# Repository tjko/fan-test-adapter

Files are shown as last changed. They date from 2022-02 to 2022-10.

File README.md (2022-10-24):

# fan-test-adapter
Adapter PCB board for easily testing PC (PWM) fans.

Adapter was created to simplify characterising PC fans. It's mainly meant for PWM fans, but can also be useful for 3-pin PC fans. Adapter also has common JST connectors for common 2-pin fans.
This adapter was used in development and testing of [Fanpico](https://github.com/tjko/fanpico/) (Fanpico is a smart PWM fan controller) to "emulate" motherboard FAN outputs.

Adapter is meant to be used with
* 3 channel programmable power supply (but will work fine with 1 or 2 channel PSUs)
* 2+ channel oscilloscope (or frequency counter)
* 2 channel signal generator

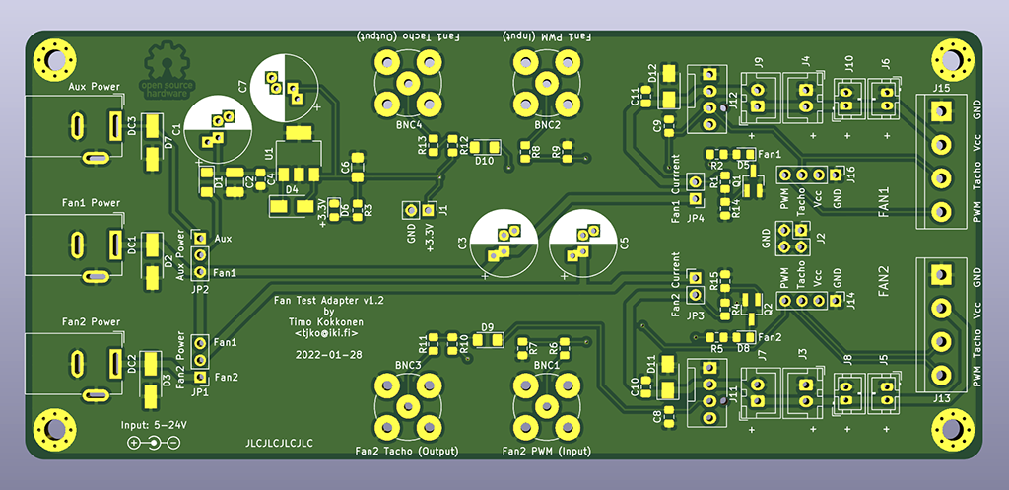
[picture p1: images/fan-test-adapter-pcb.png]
Fan Test Adapter PCB


Assembled fan test adapter:
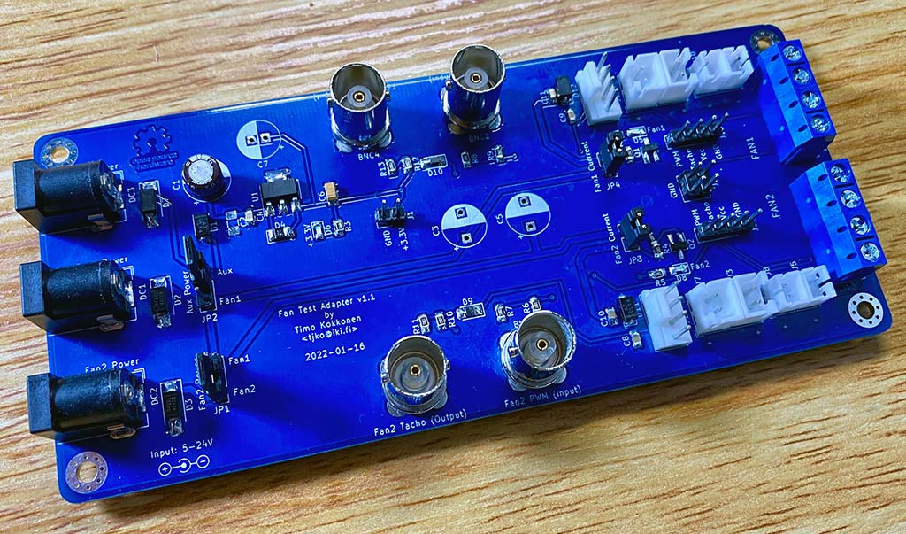
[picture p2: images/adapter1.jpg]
Assembled Fant Test Adapter


Fan test adapter in use:
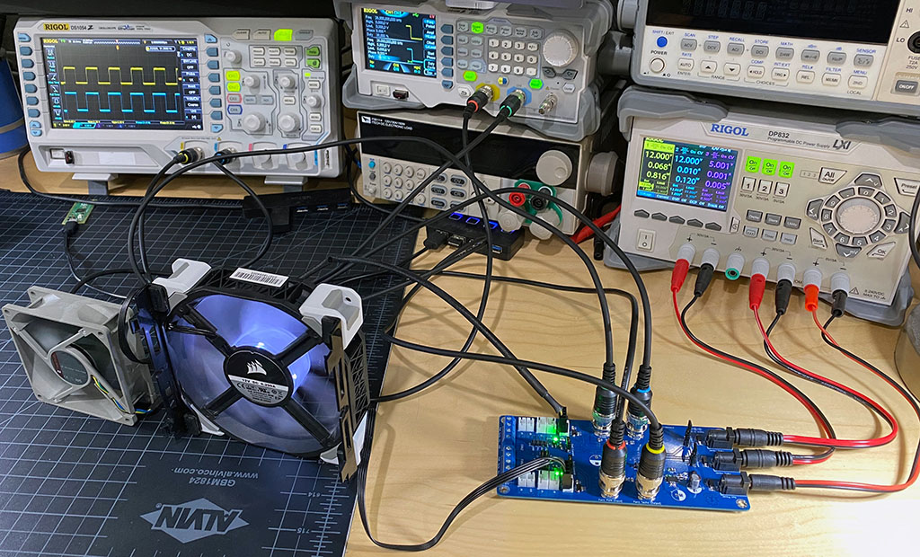
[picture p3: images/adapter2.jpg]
Fan Test Adapter in use


## Usage Notes
This is only adapter for easily testing/controlling PWM fans. If used incorrectly it could easily damage your fans, etc...

### Power Connectors
Fan Test Adapter has three DC power jacks. It can be used only with power supplied to "Fan1 Power" jack, but it may be desirable to use all three, depending on how adapter is being used.

#### AUX Power
This is can be used to power the board itself (3.3V power rail, LEDs, etc). This can be useful if doing fan power consumption measurements via measuring supplied power to Fan1/Fan2 connectors.
When using this connector make sure jumper _Aux Power_ is set to _Aux_ position (and _Fan2 Power_ jumper is set to _Fan2_ position).

Recommended supply voltage is 5V (however up to 24V can be used if needed).

#### Fan1 Power
This is used to provide power to Fan1. Additionally _Aux Power_ jumper can be set to _Fan1_ position if _AUX Power_ is not used.

Recommended supply voltage is the nominal voltage of the fan being tested (Voltage should be in range from 5V to 24V max).

#### Fan2 Power
This is used to proive power fo Fan1.  If this connector is used remember to set _Fan2 Power_ jumper to _Fan2_ position.

Recommended supply voltage is the nominal voltage of the fan being tested (Voltage should be in range from 5V to 24V max).

### Jumpers

#### Fan1 Current
Normally closed. Can be used for precise current measurement of Fan1 power consumption, by removing the jumper and connecting current meter in the pins.
#### Fan2 Current
Normally closed. Can be used for precise current measurement of Fan2 power consumption, by removing the jumper and connecting current meter in the pins.
#### Aux Power
Jumper to select whether board itself (3.3V power rail) is powered from _Fan1 Power_ or _Aux Power_ power connector.
#### Fan2 Power
Jumper to select whether Fan2 is powered from _Fan1 Power_ or _Fan2 Power_ power connector.

### BNC Connectors
#### Fan1/Fan2 PWM (Input)
Input for PWM signal to control fan speed. Typically (with PC fans) this is 25kHz PWM signal (0-5V).

#### Fan1/Fan2 Tacho (Output)
Adapter generates 3.3V TTL signal from the open collector tachometer output of the fan. So this is generally safe to be read direcly with a 3.3V (or 5V) MCU.

## Building Notes
* See [PCB](#pcb-kerbers) section for how to get PCB manufactured (currently it is only few dollars pre PCB to have these manufactured).
* List of needed components can be found here: [BOM](fan-test-adapter-bom.csv)
* Some of the components are optional (but can offer some protection) for details see: [Schematic](fan-test-adapter.pdf)

### PCB (Kerbers)
Kerber files ready to be sent to a PCB maker (like JLCPCB, etc):
* [PCB Version 1.2](kerbers/fan-test-adapter-v1.2.zip)

### Where to buy?
Currently this is only a DIY project. However PCBs are occasionally available (in limited quantities) at: [eBay](https://www.ebay.com/usr/oh6lxv)

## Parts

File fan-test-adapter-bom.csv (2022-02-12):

Ref | QTY | Value | Cmp name | Footprint | Description | Vendor | Mouser | LCSC
BNC1, BNC2, BNC3, BNC4 | 4 | 5-1634503-1 | Conn_Coaxial | Connector_Coaxial:BNC_TEConnectivity_1478204_Vertical | coaxial connector (BNC, SMA, SMB, SMC, Cinch/RCA, LEMO, ...) | TE | 571-5-1634503-1
C1 | 1 | 4.7uF 35V (DNF) | CP | Capacitor_THT:CP_Radial_D10.0mm_P2.50mm_P5.00mm
C2, | 1 | 4.7uF 35V | CP | Capacitor_SMD:C_1210_3225Metric_Pad1.42x2.65mm_HandSolder | Tantalum |  | 581-TAJB475K035R
C4, C10, C11, | 3 | 0.1uF 35V | C | Capacitor_SMD:C_0805_2012Metric_Pad1.15x1.40mm_HandSolder | Unpolarized capacitor
C6, | 1 | 10uF 16V | CP | Capacitor_SMD:C_1206_3216Metric_Pad1.42x1.75mm_HandSolder | Tantalum |  |  | C880927
C7, | 1 | 10uF 16V (DNF) | CP | Capacitor_THT:CP_Radial_D10.0mm_P2.50mm_P5.00mm
C8, C9, | 2 | 1nF | C | Capacitor_SMD:C_0805_2012Metric_Pad1.15x1.40mm_HandSolder | Unpolarized capacitor
D1, D9, D10, | 3 | SM5819PL-TP | D | Diode_SMD:D_1206_3216Metric_Pad1.42x1.75mm_HandSolder | Diode |  |  | C669023
D2, D3, D7, | 3 | SBRT5A50SA | D | Diode_SMD:D_SMA_Handsoldering | Diode |  |  | C264107
D4, D11, D12, | 3 | FM4007W | D | Diode_SMD:D_SMA | Diode |  |  | C402244
D5, D6, D8, | 3 | LED | LED | LED_SMD:LED_0805_2012Metric_Pad1.15x1.40mm_HandSolder | Light emitting diode |  |  | C434432
DC1, DC2, DC3 | 3 | DC Jack | Barrel_Jack_Switch | Connector_BarrelJack:BarrelJack_Wuerth_6941xx301002 | DC Barrel Jack with an internal switch |  |  | C720558
J3, J4, J7, J9 | 4 | JST XH | Conn_01x02_Male | Connector_JST:JST_XH_B2B-XH-A_1x02_P2.50mm_Vertical |  |  |  | C158012
J5, J6, J8, J10 | 4 | JST PH | Conn_01x02_Male | Connector_JST:JST_PH_B2B-PH-K_1x02_P2.00mm_Vertical |  |  |  | C131337
J11, J12 | 2 | 47053-1000 | Fan_CPU_4pin | Connector:FanPinHeader_1x04_P2.54mm_Vertical | CPU Fan, tacho output, PWM input, 4-pin connector | Molex | 538-47053-1000
J13, J15 | 2 | Terminal Block | Conn_01x04_Male | TerminalBlock:TerminalBlock_bornier-4_P5.08mm |  |  |  | C1509679
Q1, Q2, | 2 | 2N7002K | 2N7002K | Package_TO_SOT_SMD:SOT-23_Handsoldering | 0.38A Id, 60V Vds, N-Channel MOSFET, SOT-23 |  |  | C85047
R1, R4, | 2 | 100k | R | Resistor_SMD:R_0805_2012Metric_Pad1.15x1.40mm_HandSolder | Resistor
R2, R3, R5, | 3 | 5k | R | Resistor_SMD:R_0805_2012Metric_Pad1.15x1.40mm_HandSolder | Resistor
R6, R8, R11, R13, | 4 | 1k | R | Resistor_SMD:R_0805_2012Metric_Pad1.15x1.40mm_HandSolder | Resistor
R7, R9, | 2 | 33k | R | Resistor_SMD:R_0805_2012Metric_Pad1.15x1.40mm_HandSolder | Resistor
R10, R12, | 2 | 10k | R | Resistor_SMD:R_0805_2012Metric_Pad1.15x1.40mm_HandSolder | Resistor
R14, R15, | 2 | 1M | R | Resistor_SMD:R_0805_2012Metric_Pad1.15x1.40mm_HandSolder | Resistor
U1, | 1 | SPX2954-3.3 | SPX2954-3.3 | Package_TO_SOT_SMD:SOT-223-3_TabPin2 | 400mA Low drop-out regulator, Fixed Output 3.3V, SOT-223 |  |  | C32770
Jumpers | 4 | 2.54mm jumper |  |  |  |  |  | C5305

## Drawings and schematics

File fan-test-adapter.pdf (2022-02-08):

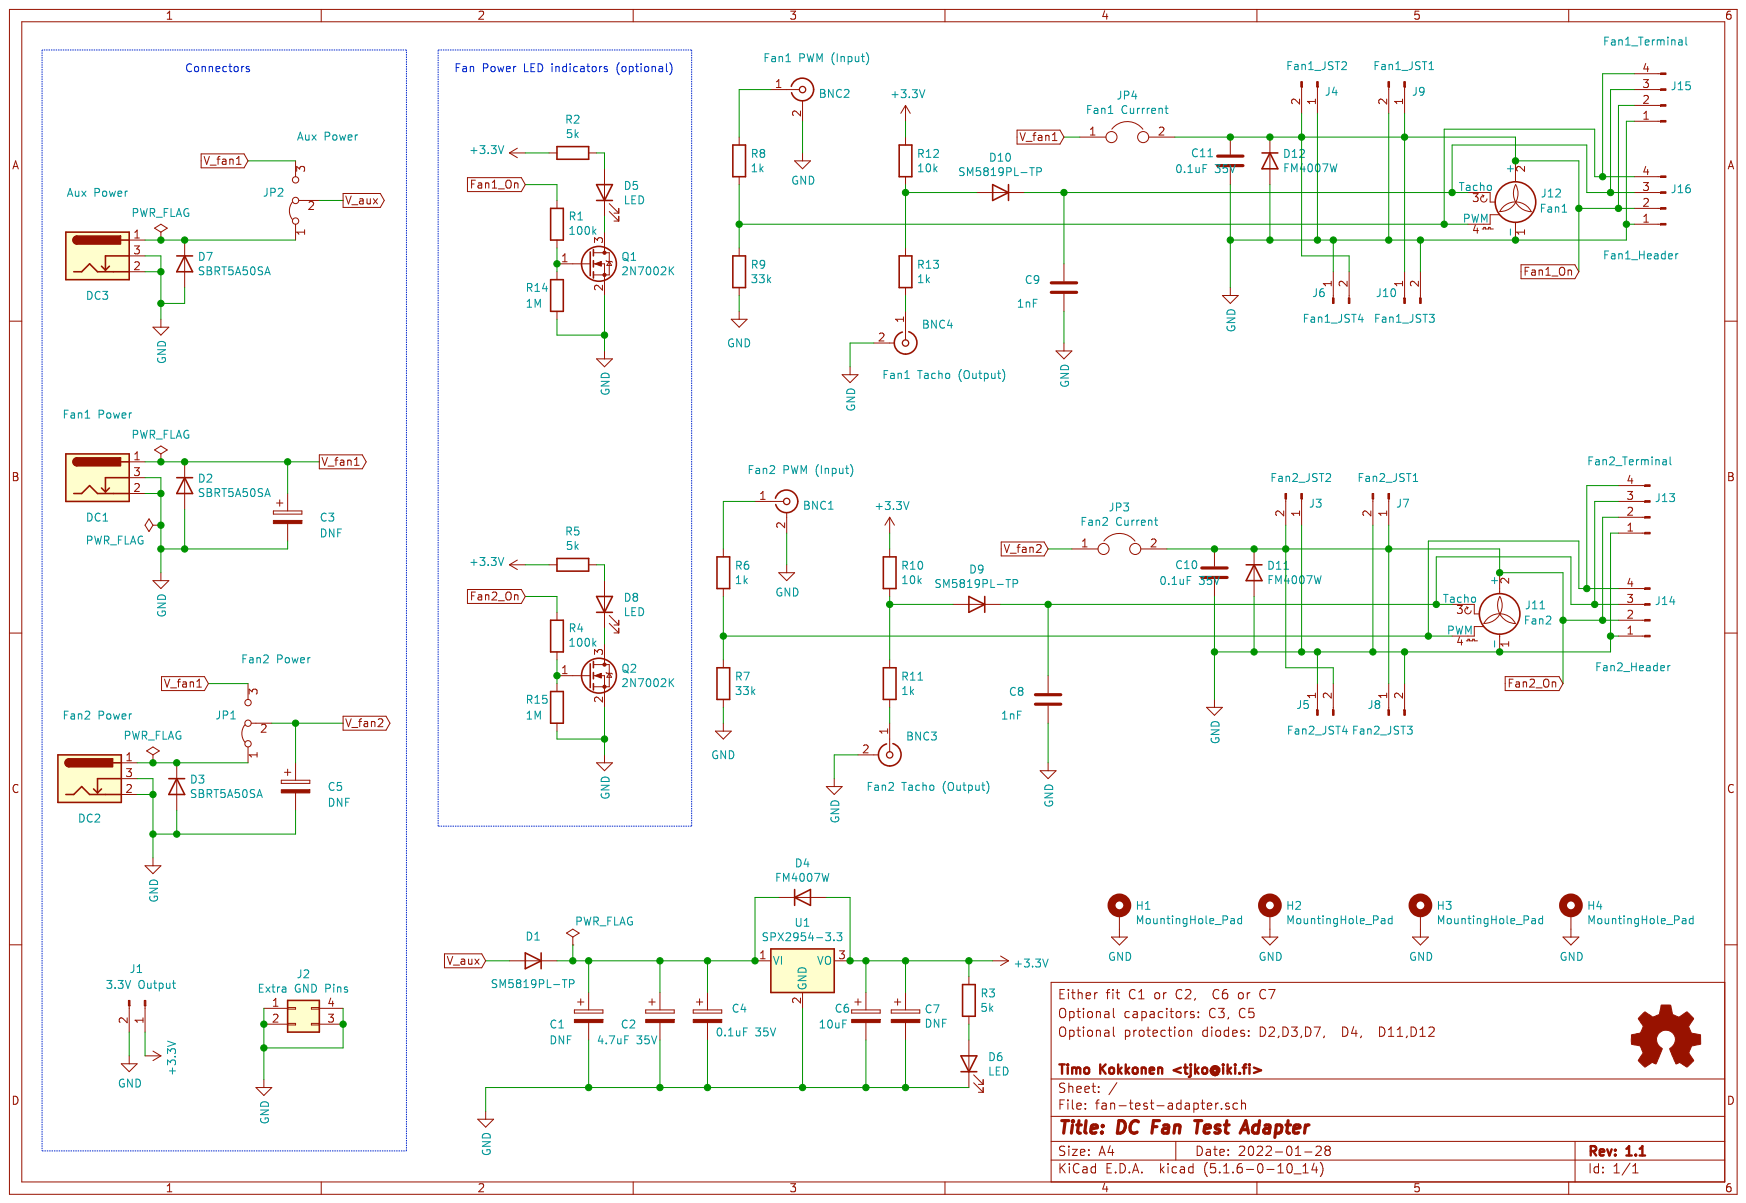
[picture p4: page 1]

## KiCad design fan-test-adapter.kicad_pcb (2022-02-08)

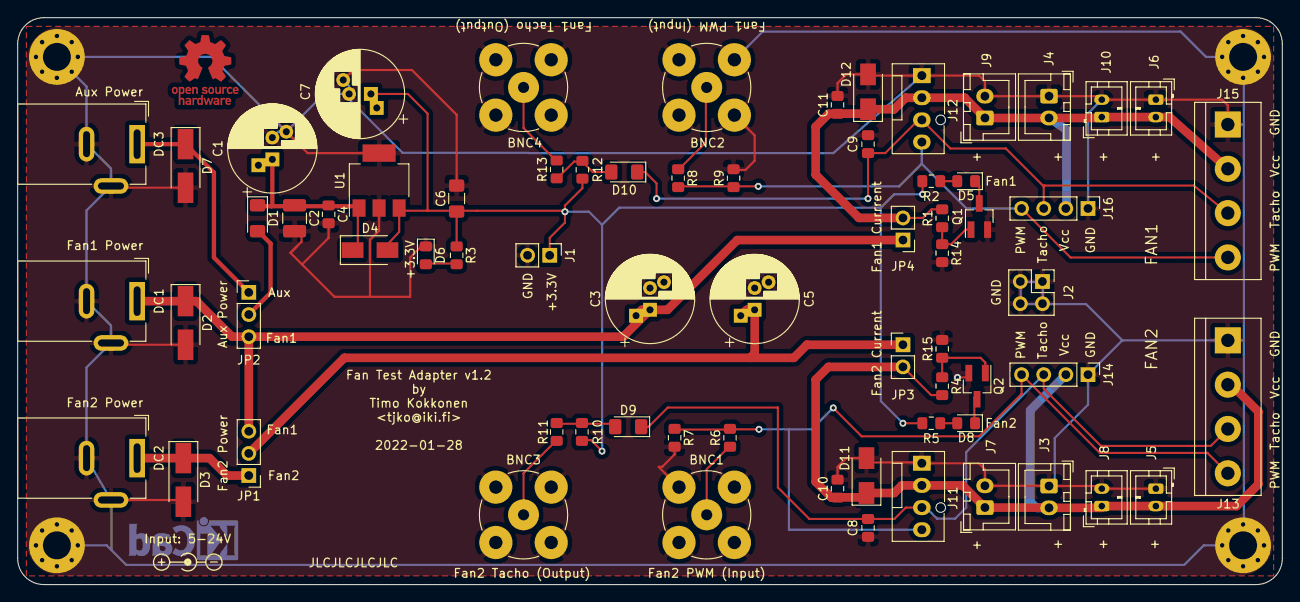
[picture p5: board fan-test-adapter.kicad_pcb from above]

Board: 2 copper layers, 145.0 x 65.0 mm, 72 parts (0 on the bottom side), 27 nets.

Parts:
BNC1: Fan2 PWM (Input); BNC_TEConnectivity_1478204_Vertical
BNC2: Fan1 PWM (Input); BNC_TEConnectivity_1478204_Vertical
BNC3: Fan2 Tacho (Output); BNC_TEConnectivity_1478204_Vertical
BNC4: Fan1 Tacho (Output); BNC_TEConnectivity_1478204_Vertical
C1: 10uF 35V; CP_Radial_D10.0mm_P2.50mm_P5.00mm
C2: 4.7uF 35V; C_1210_3225Metric_Pad1.42x2.65mm_HandSolder
C3, C5: DNF; CP_Radial_D10.0mm_P2.50mm_P5.00mm
C4: 0.1uF 35V; C_0805_2012Metric_Pad1.15x1.40mm_HandSolder
C6: 10uF; C_1206_3216Metric_Pad1.42x1.75mm_HandSolder
C7: 10uF; CP_Radial_D10.0mm_P2.50mm_P5.00mm
C8, C9: 1nF; C_0805_2012Metric_Pad1.15x1.40mm_HandSolder
C10, C11: 0.1uF; C_0805_2012Metric_Pad1.15x1.40mm_HandSolder
D1, D9, D10: SM5819PL-TP; D_1206_3216Metric_Pad1.42x1.75mm_HandSolder
D2, D3, D7: SBRT5A50SA; D_SMA_Handsoldering
D4, D11, D12: FM4007W; D_SMA
D5, D6, D8: LED; LED_0805_2012Metric_Pad1.15x1.40mm_HandSolder
DC1: Fan1 Power; BarrelJack_Wuerth_6941xx301002
DC2: Fan2 Power; BarrelJack_Wuerth_6941xx301002
DC3: Aux Power; BarrelJack_Wuerth_6941xx301002
H1, H2, H3, H4: MountingHole_Pad; MountingHole_3.2mm_M3_Pad_Via
J1: 3.3V Output; PinHeader_1x02_P2.54mm_Vertical
J2: Extra GND Pins; PinHeader_2x02_P2.54mm_Vertical
J3: Fan2_JST2; JST_XH_B2B-XH-A_1x02_P2.50mm_Vertical
J4: Fan1_JST2; JST_XH_B2B-XH-A_1x02_P2.50mm_Vertical
J5: Fan2_JST4; JST_PH_B2B-PH-K_1x02_P2.00mm_Vertical
J6: Fan1_JST4; JST_PH_B2B-PH-K_1x02_P2.00mm_Vertical
J7: Fan2_JST1; JST_XH_B2B-XH-A_1x02_P2.50mm_Vertical
J8: Fan2_JST3; JST_PH_B2B-PH-K_1x02_P2.00mm_Vertical
J9: Fan1_JST1; JST_XH_B2B-XH-A_1x02_P2.50mm_Vertical
J10: Fan1_JST3; JST_PH_B2B-PH-K_1x02_P2.00mm_Vertical
J11: Fan2; FanPinHeader_1x04_P2.54mm_Vertical
J12: Fan1; FanPinHeader_1x04_P2.54mm_Vertical
J13: Fan2_Terminal; TerminalBlock_bornier-4_P5.08mm
J14: Fan2_Header; PinHeader_1x04_P2.54mm_Vertical
J15: Fan1_Terminal; TerminalBlock_bornier-4_P5.08mm
J16: Fan1_Header; PinHeader_1x04_P2.54mm_Vertical
JP1: Fan2 Power; PinHeader_1x03_P2.54mm_Vertical
JP2: Aux Power; PinHeader_1x03_P2.54mm_Vertical
JP3: Fan2 Current; PinHeader_1x02_P2.54mm_Vertical
JP4: Fan1 Currrent; PinHeader_1x02_P2.54mm_Vertical
Q1, Q2: 2N7002K; SOT-23_Handsoldering
R1, R4, R10, R12: 10k; R_0805_2012Metric_Pad1.15x1.40mm_HandSolder
R2, R3, R5: 5k; R_0805_2012Metric_Pad1.15x1.40mm_HandSolder
R6, R8, R11, R13: 1k; R_0805_2012Metric_Pad1.15x1.40mm_HandSolder
R7, R9: 33k; R_0805_2012Metric_Pad1.15x1.40mm_HandSolder
R14, R15: 1M; R_0805_2012Metric_Pad1.15x1.40mm_HandSolder
U1: SPX2954-3.3; SOT-223-3_TabPin2

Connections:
+3V3: C6.1, C7.1, D4.2, J1.1, R2.1, R3.1, R5.1, R10.1, R12.1, U1.3
Fan1_On: C11.1, D12.1, J4.2, J6.2, J9.1, J10.1, J12.2, J15.2, J16.2, JP4.2, R1.2
Fan2_On: C10.1, D11.1, J3.2, J5.2, J7.1, J8.1, J11.2, J13.2, J14.2, JP3.2, R4.2
GND: BNC1.2, BNC2.2, BNC3.2, BNC4.2, C1.2, C2.2, C3.2, C4.2, C5.2, C6.2, C7.2, C8.2, C9.2, C10.2, C11.2, D2.2, D3.2, D6.1, D7.2, D11.2, D12.2, DC1.2, DC1.3, DC2.2, DC2.3, DC3.2, DC3.3, H1.1, H2.1, H3.1, H4.1, J1.2, J2.1, J2.2, J2.3, J2.4, J3.1, J4.1, J5.1, J6.1, J7.2, J8.2, J9.2, J10.2, J11.1, J12.1, J13.1, J14.1, J15.1, J16.1, Q1.2, Q2.2, R7.2, R9.2, R14.2, R15.2, U1.2
unnamed: BNC1.1, R6.1
unnamed: BNC2.1, R8.1
unnamed: BNC3.1, R11.2
unnamed: BNC4.1, R13.2
unnamed: C1.1, C2.1, C4.1, D1.1, D4.1, U1.1
unnamed: C8.1, D9.1, J11.3, J13.3, J14.3
unnamed: C9.1, D10.1, J12.3, J15.3, J16.3
unnamed: D3.1, DC2.1, JP1.1
unnamed: D5.1, Q1.3
unnamed: D5.2, R2.2
unnamed: D6.2, R3.2
unnamed: D7.1, DC3.1, JP2.1
unnamed: D8.1, Q2.3
unnamed: D8.2, R5.2
unnamed: D9.2, R10.2, R11.1
unnamed: D10.2, R12.2, R13.1
unnamed: J11.4, J13.4, J14.4, R6.2, R7.1
unnamed: J12.4, J15.4, J16.4, R8.2, R9.1
unnamed: Q1.1, R1.1, R14.1
unnamed: Q2.1, R4.1, R15.1
V_aux: D1.2, JP2.2
V_fan1: C3.1, D2.1, DC1.1, JP1.3, JP2.3, JP4.1
V_fan2: C5.1, JP1.2, JP3.1

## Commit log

2022-02-08 Add KiCad project files.
    [fan-test-adapter.kicad_pcb, fan-test-adapter.sch]
2022-02-08 Add kerbers for v1.2 PCB.
2022-02-08 Add PDF of the schematic.
2022-02-08 Correct component values.
    [fan-test-adapter.sch]
2022-02-12 Add bill of materials (BOM).
    [fan-test-adapter-bom.csv]
2022-02-12 Add part number for DC jack.
    [fan-test-adapter-bom.csv]
